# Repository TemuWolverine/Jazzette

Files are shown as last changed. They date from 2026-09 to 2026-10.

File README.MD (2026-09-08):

# Jazzette Player
> [!WARNING]  
> **This is work in progress**.  
> I am using this readme as a bit of a scratchpad of parts. Don't assume they're the final parts until this announcement is removed.  
> **This is work in progress**.

I got nerd sniped over on [reddit](https://www.reddit.com/r/homeassistant/comments/1vtjl21/comment/p4xepdl/).  


## PCB
PCB prototype has now been sent off for manufacture.  
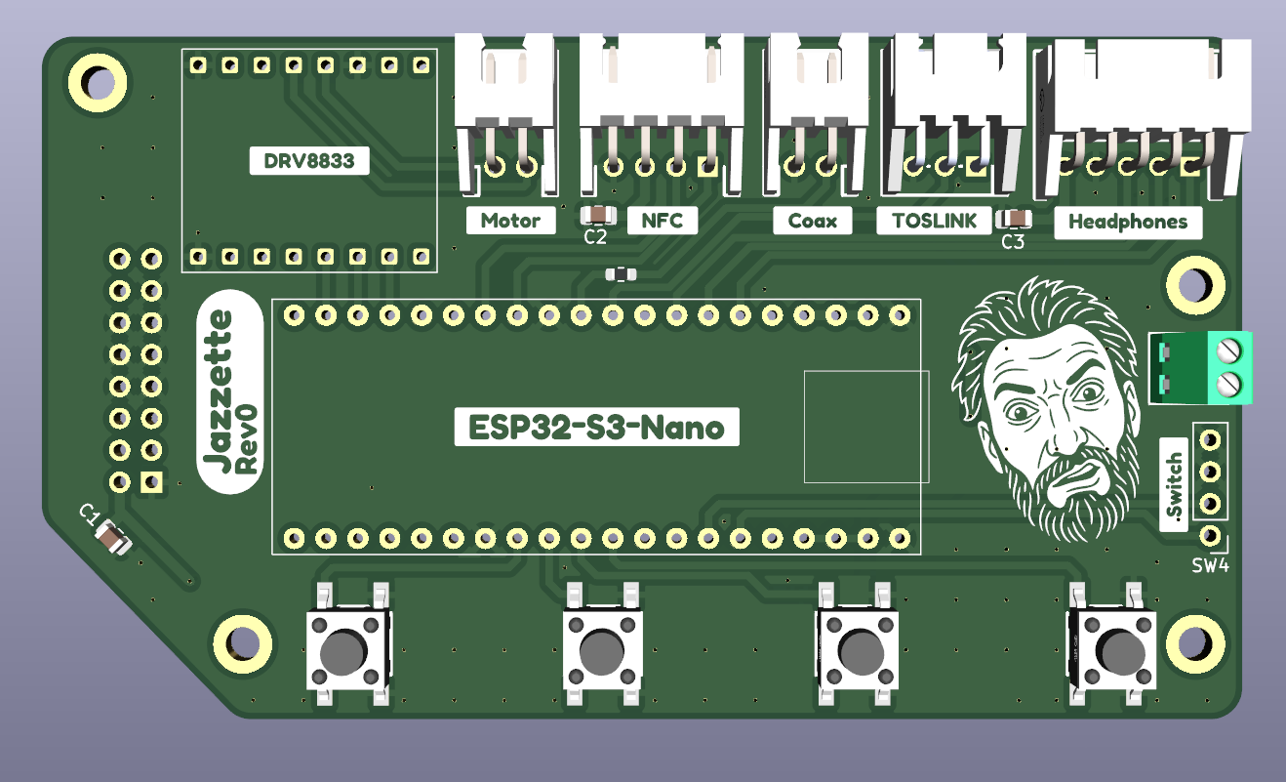
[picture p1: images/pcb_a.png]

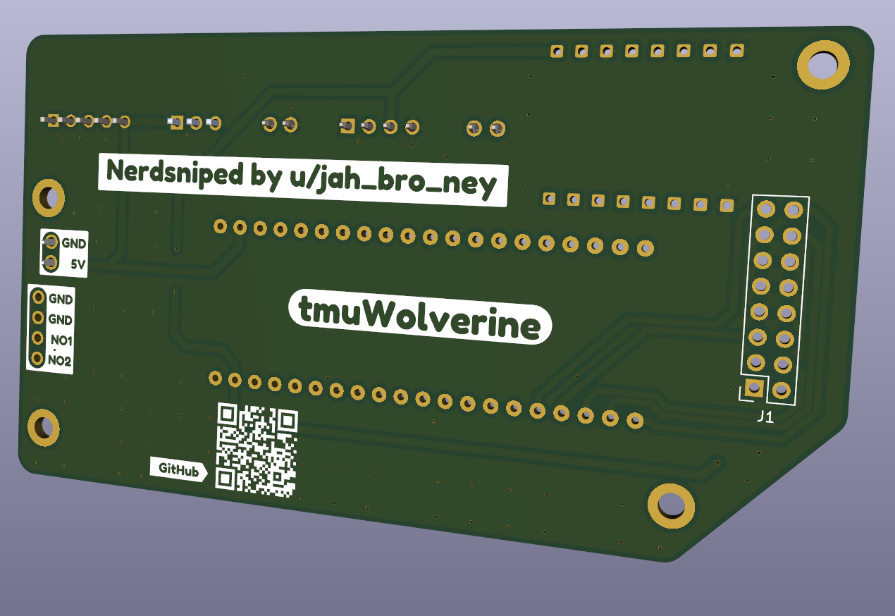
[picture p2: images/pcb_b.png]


## Shell
The shell is still in active development, but here is a render of the vague idea, mimicking the old cassettecorders. 
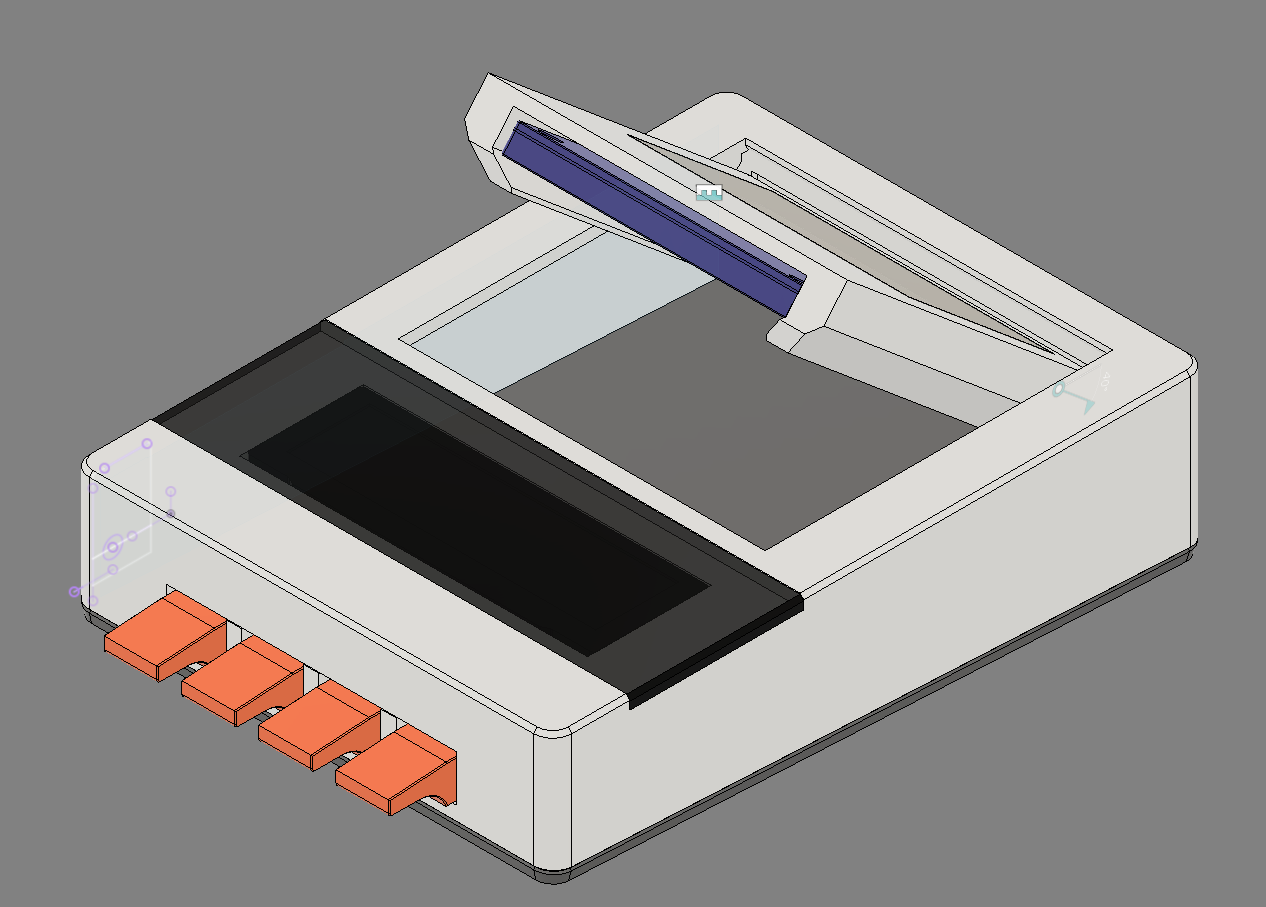
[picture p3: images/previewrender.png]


## BOM

| Part | Quantity | Note |
|---|---|----- |
| [ESP32 S3 Nano](https://s.click.aliexpress.com/e/_c4tw9Hh5) | 1 ||
| [DRV8833](https://www.amazon.com.au/Xlihdzum-DRV8833-H-Bridge-Driver-Module/dp/B0GHQ6YCLV) | 1 |  |
| [N20 DC motor](https://www.aliexpress.com/item/32385310725.html) | 1 |  3v |
| [PCM5100A breakout](https://www.aliexpress.com/item/1005008889469187.html) | 1 | Headphone amp |
| [NFC breakout](https://s.click.aliexpress.com/e/_c3WaMQwL)  | 1 |  |
| [3.12" OLED (256x54) SPI](https://s.click.aliexpress.com/e/_c2IVFyqT) | 1 | White looks best IMO |
| [TOSLINK transmitter](https://s.click.aliexpress.com/e/_c3J5kkCf) | 1 |  |
| [RCA plug](https://s.click.aliexpress.com/e/_c3TPM0xV) | 1 | |
| 480ohm resistor | 1 | 0803 SMD package, used for coax |
| 0.1uF capacitor | 3 | 0803 SMD package, used for decoupling |
| 6x6 tactile switch | 4  | SMD|
| 2 pin JST XH right angle | 2 | S2B-XH-A(LF)(SN) |
| 3 pin JST XH right angle | 1 | S3B-XH-A(LF)(SN) |
| 4 pin JST XH right angle | 1 | S4B-XH-A(LF)(SN) |
| 5 pin JST XH right angle | 1 | S5B-XH-A(LF)(SN) |
| [3-way switch](https://www.aliexpress.com/item/1005006780672833.html) | 1 |  |
| 3mm Translucent Black Acrylic | 1 | overlaid over screen |
| 3mm clear acrylic | 1 | Tape door |
| 3d printing filament | | |

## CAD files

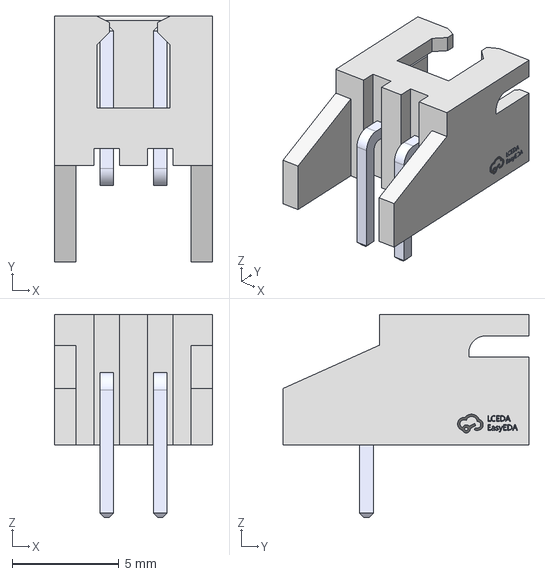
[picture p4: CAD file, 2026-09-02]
PCB/EASYEDA_MODELS/CONN-TH_S2B-XH-A-1-LF-SN.step
7.40 x 11.5 x 9.50 mm

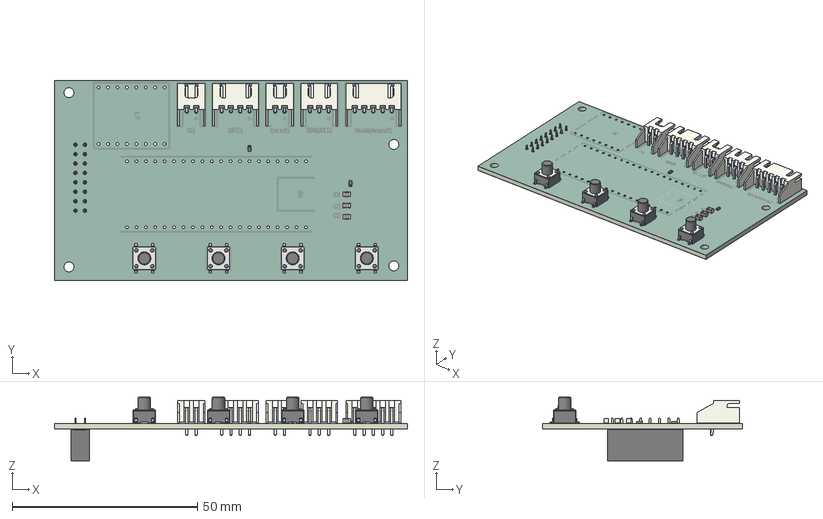
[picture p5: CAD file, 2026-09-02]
PCB/jazzette.step
95.2 x 54.0 x 17.2 mm
C_0805_2012Metric x 3
Tactile Switch 6mm - SMT x 4
JST_S3B_XH_A_1
JST_S2B_XH_A_1 x 2
R_0603_1608Metric x 2
JST_S5B_XH_A_1
JST_S4B_XH_A_1
PinSocket_2x08_P2.54mm_Vertical
jaz6D58_silkscreen x 2
jaz6D58_soldermask x 2
jaz6D58_PCB

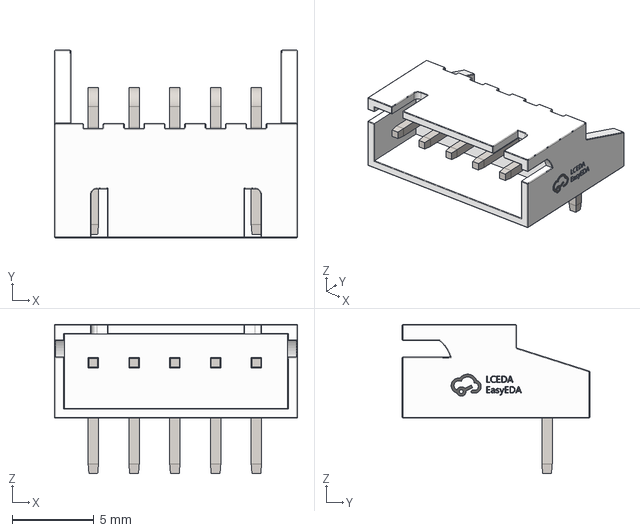
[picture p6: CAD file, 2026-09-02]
PCB/EASYEDA_MODELS/CONN-TH_5P-P2.50_S5B-XH-A-LF-SN.step
14.9 x 11.5 x 9.15 mm

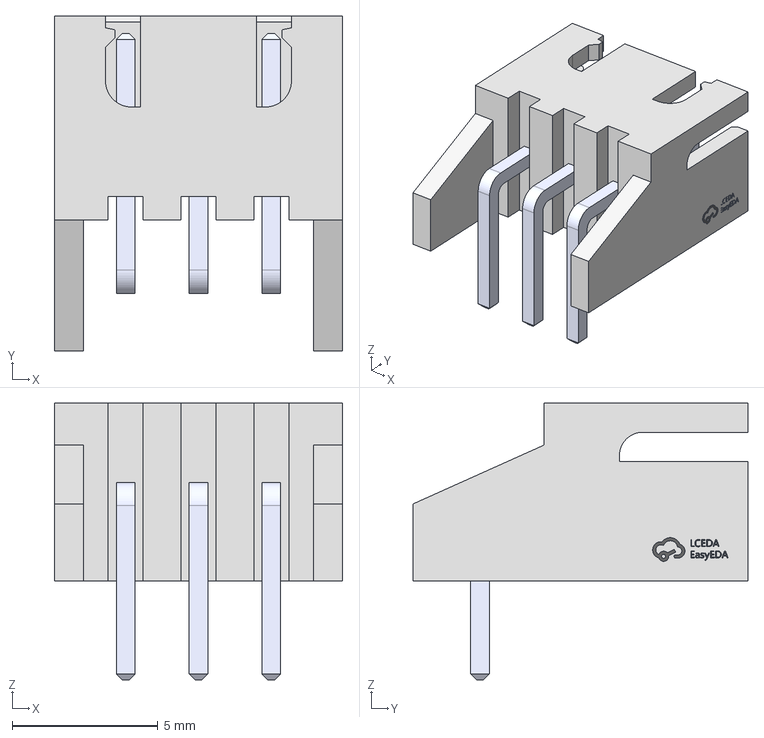
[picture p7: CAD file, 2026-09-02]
PCB/EASYEDA_MODELS/CONN-TH_S3B-XH-A-LF-SN.step
9.90 x 11.5 x 9.50 mm

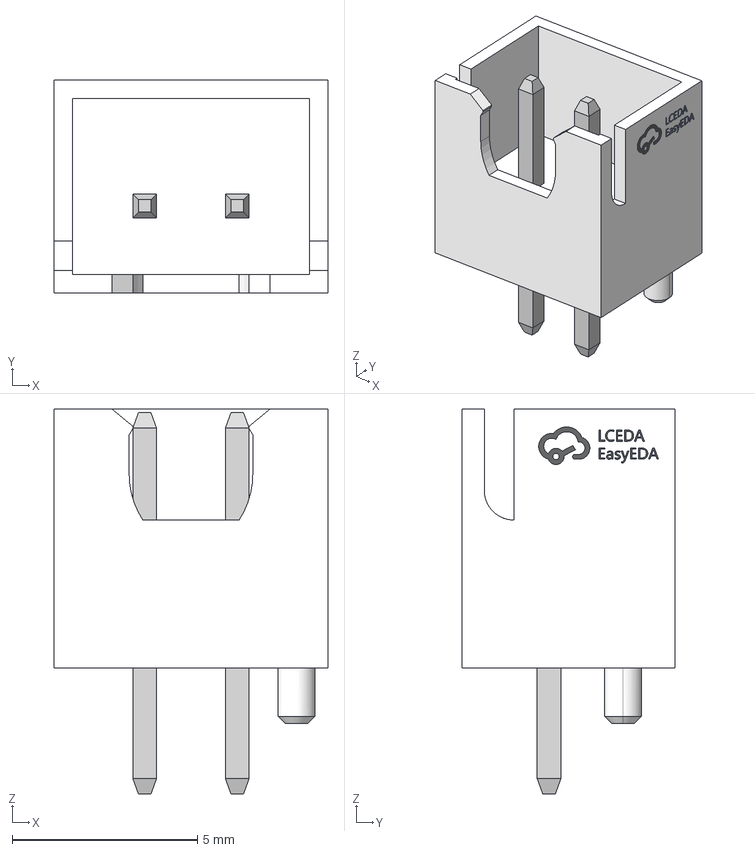
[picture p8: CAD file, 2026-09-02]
PCB/EASYEDA_MODELS/CONN-TH_B2B-XH-AM-LF-SN.step
7.40 x 5.75 x 10.4 mm

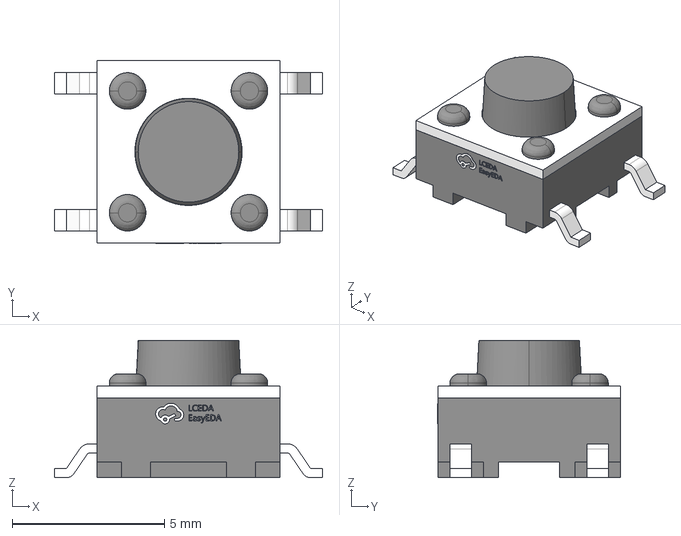
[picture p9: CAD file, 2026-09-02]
PCB/EASYEDA_MODELS/SW-SMD_SH-6X6X4.5H-TP.step
8.80 x 6.01 x 4.51 mm

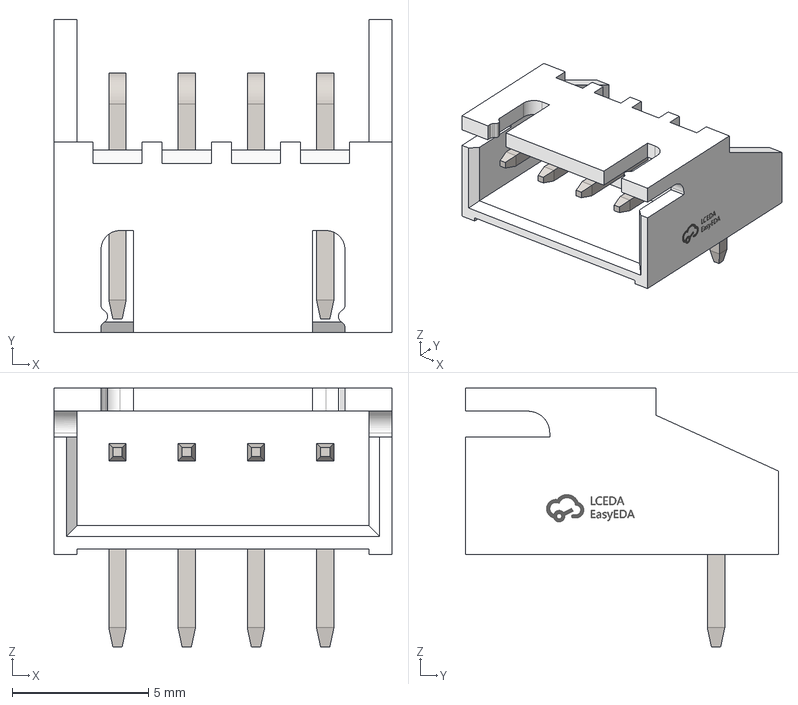
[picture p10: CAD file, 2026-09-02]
PCB/EASYEDA_MODELS/CONN-TH_S4B-XH-A-LF-SN.step
12.4 x 11.5 x 9.50 mm

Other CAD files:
PCB/EASYEDA_MODELS/CONN-TH_S2B-XH-A-LF-SN.step

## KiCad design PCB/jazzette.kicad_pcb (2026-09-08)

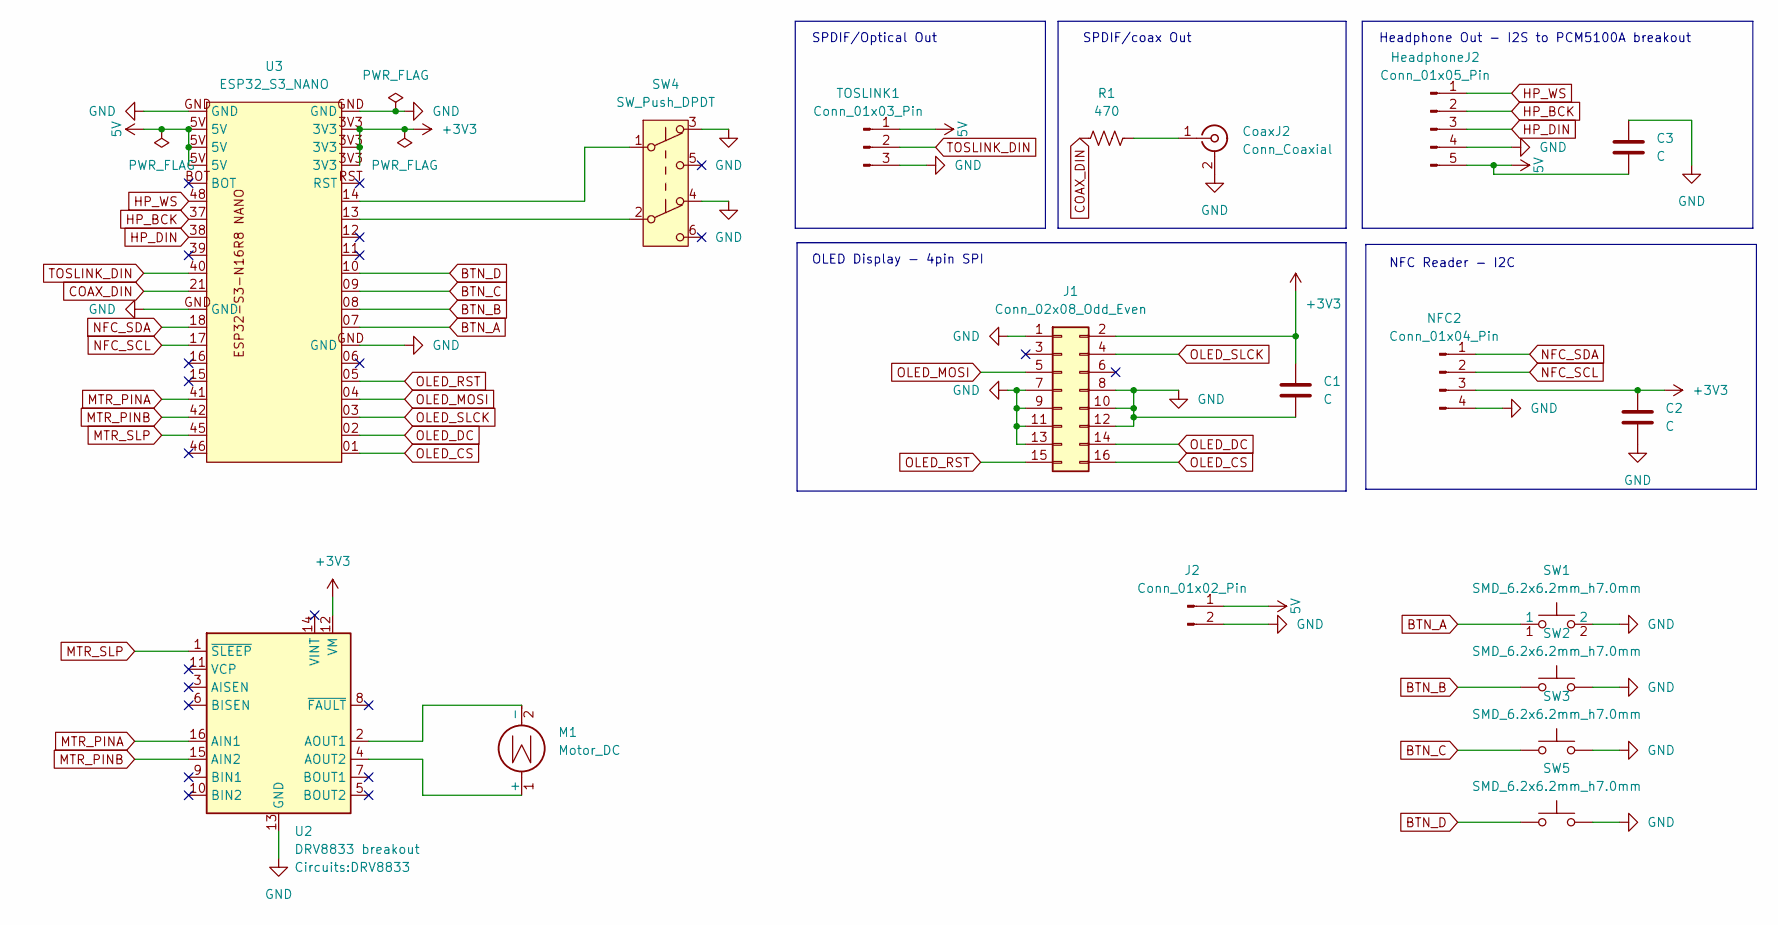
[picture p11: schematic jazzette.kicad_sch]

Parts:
C1, C2, C3: C; C_0805_2012Metric
CoaxJ2: Conn_Coaxial; CONN-TH_S2B-XH-A-LF-SN
HeadphoneJ2: Conn_01x05_Pin; CONN-TH_S5B-XH-A-LF-SN
J1: Conn_02x08_Odd_Even; PinSocket_2x08_P2.54mm_Vertical
J2: Conn_01x02_Pin; CONN-TH_DB125-2.54-2P-GN
M1: Motor_DC; CONN-TH_S2B-XH-A-LF-SN
NFC2: Conn_01x04_Pin; CONN-TH_S4B-XH-A-LF-SN
R1: 470; R_0603_1608Metric
SW1, SW2, SW3, SW5: SMD_6.2x6.2mm_h7.0mm; SW-SMD_SH-6X6X4.5H-TP; Mfg Part# 679-2384-2-ND
SW4: SW_Push_DPDT; PinHeader_1x04_P2.54mm_Vertical
TOSLINK1: Conn_01x03_Pin; CONN-TH_S3B-XH-A-LF-SN
U2: DRV8833 breakout; DRV8833
U3: ESP32_S3_NANO

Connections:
5V: C3.1, HeadphoneJ2.5, J2.1, TOSLINK1.1, U3.5V
+3V3: C1.1, C2.1, J1.2, NFC2.3, U2.12 (VM), U3.3V3
BTN_A: SW1.1, U3.07
BTN_B: SW2.1, U3.08
BTN_C: SW3.1, U3.09
BTN_D: SW5.1, U3.10
COAX_DIN: R1.2, U3.21
GND: C1.2, C2.2, C3.2, CoaxJ2.2 (Ext), HeadphoneJ2.4, J1.1, J1.7, J1.8, J1.9, J1.10, J1.11, J1.12, J1.13, J2.2, NFC2.4, SW1.2, SW2.2, SW3.2, SW4.3 (A), SW4.4 (A), SW5.2, TOSLINK1.3, U2.13 (GND), U3.GND
HP_BCK: HeadphoneJ2.2, U3.37
HP_DIN: HeadphoneJ2.3, U3.38
HP_WS: HeadphoneJ2.1, U3.48
MTR_PINA: U2.16 (AIN1), U3.41
MTR_PINB: U2.15 (AIN2), U3.42
MTR_SLP: U2.1 (~SLEEP), U3.45
NFC_SCL: NFC2.2, U3.17
NFC_SDA: NFC2.1, U3.18
unnamed: CoaxJ2.1 (In), R1.1
unnamed: M1.1 (+), U2.4 (AOUT2)
unnamed: M1.2 (-), U2.2 (AOUT1)
unnamed: SW4.1 (B), U3.14
unnamed: SW4.2 (B), U3.13
OLED_CS: J1.16, U3.01
OLED_DC: J1.14, U3.02
OLED_MOSI: J1.5, U3.04
OLED_RST: J1.15, U3.05
OLED_SLCK: J1.4, U3.03
TOSLINK_DIN: TOSLINK1.2, U3.40

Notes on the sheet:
SPDIF/coax Out
SPDIF/Optical Out
Headphone Out - I2S to PCM5100A breakout
NFC Reader - I2C
OLED Display - 4pin SPI

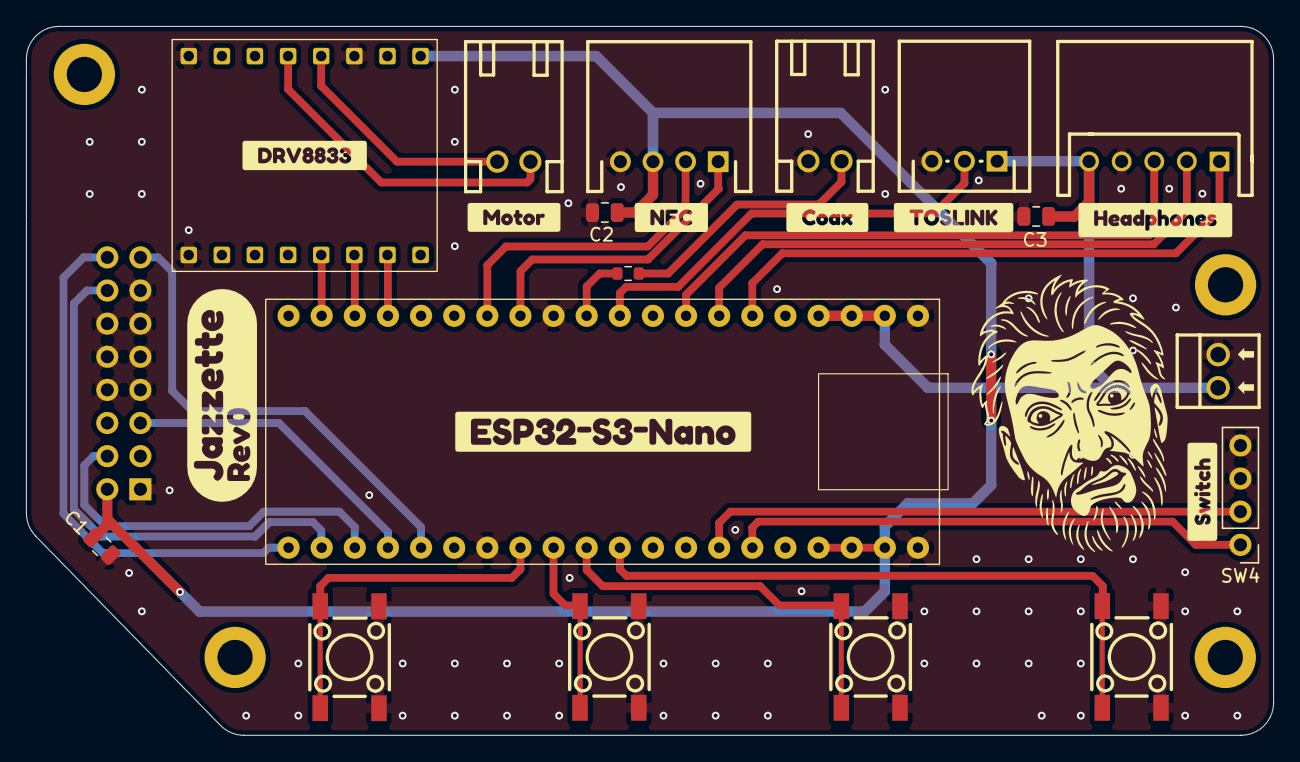
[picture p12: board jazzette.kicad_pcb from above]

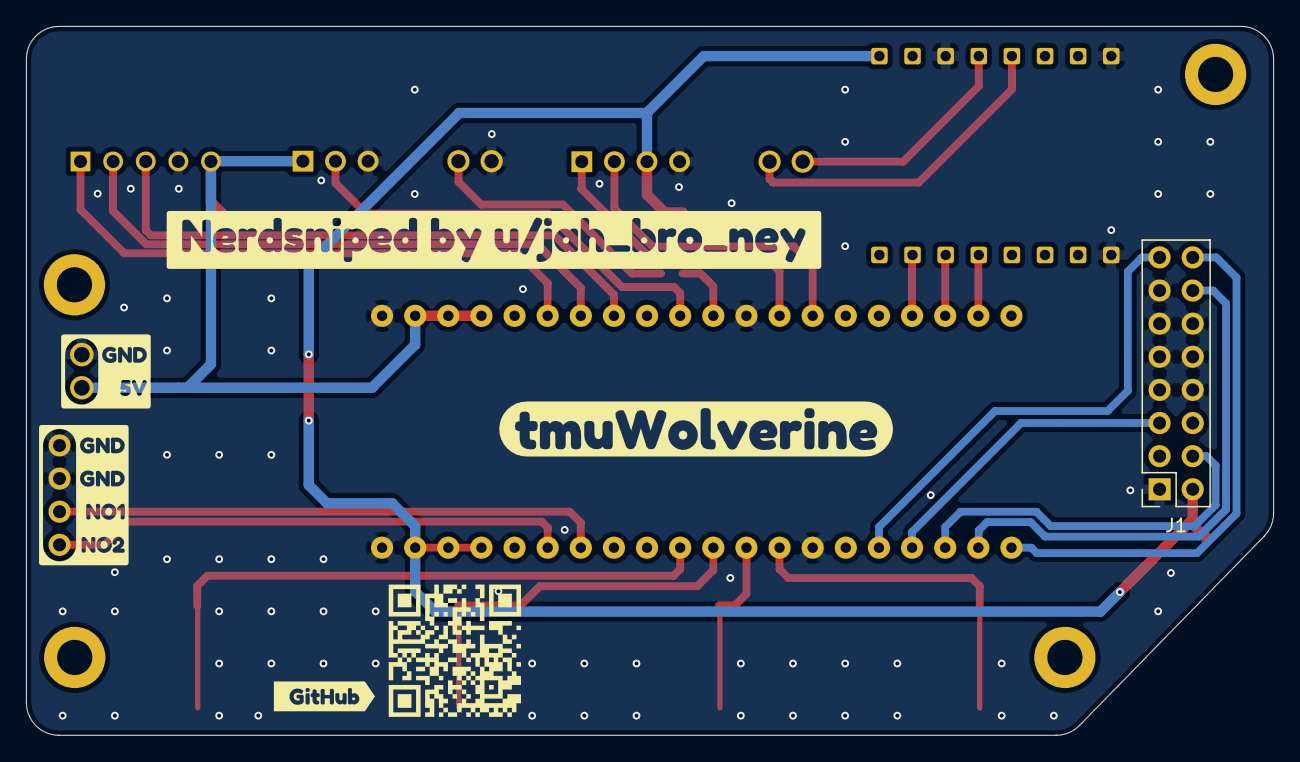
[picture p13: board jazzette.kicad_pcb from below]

Board: 2 copper layers, 95.6 x 54.4 mm, 33 parts (7 on the bottom side), 27 nets.

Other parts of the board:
kobee-studio-6A9C82AE: Kobee Studio; kobee-studio-6A9C8293
kobee-studio-6A9DE86C: Kobee Studio; kobee-studio-6A96C1A4
kobee-studio-6A9E5BD7: Kobee Studio; kobee-studio-6A9E5478
kobee-studio-6A9E5E3B: Kobee Studio; kobee-studio-6A9E5C65
kobee-studio-6A9E54C5: Kobee Studio; kobee-studio-6A9E54C5
kobee-studio-6A9E54DB, kobee-studio-6A9E55B7, kobee-studio-6A9E550D, kobee-studio-6A9E5502, kobee-studio-6A9E5517: Kobee Studio; kobee-studio-6A9E54DB
kobee-studio-6A9F86BB: Kobee Studio; kobee-studio-6A9F86BB
kobee-studio-6A9F8757: Kobee Studio; kobee-studio-6A9F8711
kobee-studio-6A97AC47: Kobee Studio; kobee-studio-6A97AC2D
kobee-studio-6A97AC75: Kobee Studio; kobee-studio-6A97AC75
kobee-studio-6A97C0E1: Kobee Studio; kobee-studio-6A97ABF4

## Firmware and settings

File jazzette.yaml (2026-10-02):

substitutions:
  startup_sound_file: Home_Connected
  media_sample_rate: 44100
  
  friendly_name: yeolderadio
  device_name: yeolderadio

  clk_pin: GPIO03
  mosi_pin: GPIO04
  dc_pin: GPIO02
  cs_pin: GPIO01
  rst_pin: GPIO05

  btna_pin: GPIO07
  btnb_pin: GPIO08
  btnc_pin: GPIO09
  btnd_pin: GPIO10

  mtr_a: GPIO41
  mtr_b: GPIO42
  mtr_slp: GPIO45

  nfc_sda: GPIO18
  nfc_scl: GPIO17

  headphone_ws: GPIO48
  headphone_bck: GPIO37
  headphone_din: GPIO38
  
  toslink_din: GPIO40
  coax_din: GPIO21

  threewayswitcha: GPIO13
  threewayswitchb: GPIO14
packages:
  esphome_templates:
    url: https://github.com/TemuWolverine/esphome_templates
    ref: main
    refresh: 1s
    files:
      - esphome_boilerplate.yaml
      - boards/esp32_s3_nano.yaml
        
esphome:
  name: esphome-web-fc09d0
  on_boot:
    priority: -100
    then:
      - script.execute: update_selector

# Enable logging
logger:

# Enable Home Assistant API
api:

# Allow Over-The-Air updates
ota:
  - platform: esphome

wifi:
  ssid: !secret wifi_ssid
  password: !secret wifi_password

globals:
  - id: selector_state
    type: int
    restore_value: no
    initial_value: '1'
  
font:
    # gfonts://family[@weight]
  - file: "gfonts://Roboto"
    id: myfont
    size: 20
  - file: "gfonts://Roboto"
    id: font_title
    size: 14

  - file: "gfonts://Roboto"
    id: font_small
    size: 9

spi:
  clk_pin: ${clk_pin}
  mosi_pin: ${mosi_pin}
  
display:
  - platform: ssd1322_spi
    model: "SSD1322 256x64"
    reset_pin: ${rst_pin}
    cs_pin: ${cs_pin}
    dc_pin: ${dc_pin}
    lambda: |-
            // Example data for now
            std::string title  = "The Piano Has Been Drinking (Not Me)";
            std::string artist = "Tom Waits";
            std::string album  = "Small Change";
      
            int elapsed = 102;   // seconds
            int duration = 220;  // seconds
      
            // Track title
            it.print(0, 0, id(font_title), title.c_str());
      
            // Artist
            it.print(0, 17, id(font_small), artist.c_str());
      
            // Album
            //it.print(0, 29, id(font_small), album.c_str());
      
            // Progress bar
            const int bar_x = 0;
            const int bar_y = 44;
            const int bar_w = 256;
            const int bar_h = 5;
      
            it.rectangle(bar_x, bar_y, bar_w, bar_h);
      
            float progress = 0.0f;
      
            if (duration > 0) {
              progress = (float) elapsed / (float) duration;
            }
      
            int progress_w = (int)((bar_w - 2) * progress);
      
            it.filled_rectangle(
              bar_x + 1,
              bar_y + 1,
              progress_w,
              bar_h - 2
            );
      
            // Convert times to mm:ss
            int elapsed_min = elapsed / 60;
            int elapsed_sec = elapsed % 60;
      
            int duration_min = duration / 60;
            int duration_sec = duration % 60;
      
            char elapsed_text[8];
            char duration_text[8];
      
            snprintf(
              elapsed_text,
              sizeof(elapsed_text),
              "%d:%02d",
              elapsed_min,
              elapsed_sec
            );
      
            snprintf(
              duration_text,
              sizeof(duration_text),
              "%d:%02d",
              duration_min,
              duration_sec
            );
      
            // Time
            it.print(
              0,
              52,
              id(font_small),
              elapsed_text
            );
      
            it.print(
              256,
              52,
              id(font_small),
              TextAlign::TOP_RIGHT,
              duration_text
            );
output:
- platform: ledc
  id: motor_enable
  pin: ${mtr_slp}
  
- platform: ledc
  id: motor_forward_pin
  pin: ${mtr_a}
  
- platform: ledc
  id: motor_reverse_pin
  pin: ${mtr_b}
 
fan:
  - platform: hbridge
    id: my_fan
    name: "Living Room Fan"
    pin_a: motor_forward_pin #${motor_forward_pin}
    pin_b: motor_reverse_pin
    enable_pin: motor_enable
    decay_mode: slow   # slow decay mode (coasting) or fast decay (braking).      

i2c:
  sda: ${nfc_sda}
  scl: ${nfc_scl}

pn532_i2c:
  update_interval: 1s
  on_tag:
    then:
    - text_sensor.template.publish:
        id: rfid_tag
        state: !lambda 'return x;'
#    - fan.toggle: my_fan
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

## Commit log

2026-09-08 board sent to mfg
    [jazzette.kicad_pcb, jazzette.kicad_sch]
2026-10-02 should use the selector correctly
    [jazzette.yaml]
2026-11-07 CAD files (3mf + f3z)
